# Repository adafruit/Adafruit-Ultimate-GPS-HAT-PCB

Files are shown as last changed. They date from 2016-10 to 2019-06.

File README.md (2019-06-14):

## Adafruit Ultimate GPS HAT PCB

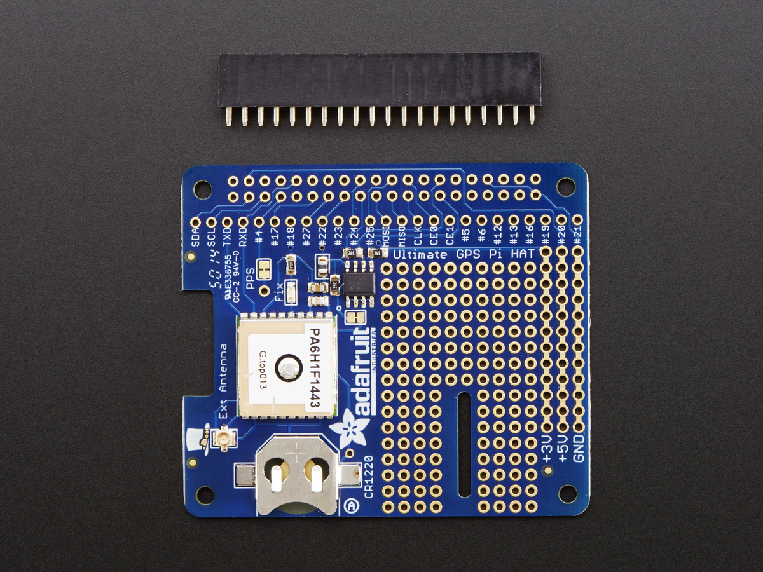
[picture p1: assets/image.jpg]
<a href="http://www.adafruit.com/products/2324"><br/>
Click here to purchase one from the Adafruit shop
</a>

PCB files for the Adafruit Ultimate GPS HAT. Format is EagleCAD schematic and board layout
- http://www.adafruit.com/product/2324

This new HAT from Adafruit adds our celebrated Ultimate GPS on it, so you can add precision time and location to your Raspberry Pi Model Pi 3, Pi Zero, A+, B+, or Pi 2 & 3

Here's the low-down on the GPS module:

-165 dBm sensitivity, 10 Hz updates, 66 channels
Only 20mA current draw
Built in Real Time Clock (RTC) - slot in a CR1220 backup battery for 7-years or more of timekeeping even if the Raspberry Pi is off!
PPS output on fix, by default connected to pin #4
Internal patch antenna which works quite well when used outdoors + u.FL connector for external active antenna for when used indoors or in locations without a clear sky view
Fix status LED blinks to let you know when the GPS has determined the current coordinates
We spun up a HAT based on our Ultimate GPS, added a coin-cell holder for RTC usage, break-outs for all the Raspberry Pi's extra pins, and plenty of prototyping area for adding LEDs, sensors, and more.

Please note, this HAT takes over the Raspberry Pi's hardware UART to send/receive data to and from the GPS module. So, if you need to use the RX/TX pins with a console cable, you cannot also use this HAT. Instead, you'll have to use a composite or HDMI monitor and keyboard to log in, or use ssh to connect over the network to your Pi. Read up on our tutorial for more information on how to use this fine HAT

Comes as a fully assembled GPS + PCB and an additional 2x20 GPIO header. Some light soldering is required to attach the 2x20 GPIO header to the HAT but it's fast and easy for anyone with a soldering iron and solder. You can also swap the plain female header we have with a 'stacky' type that lets you plug in a hat or GPIO cable on top or a slim ultra-low-profile header.

To make air-shipping eaiser, this HAT does not come with a 12mm coin battery! 

### License

Adafruit invests time and resources providing this open source design, please support Adafruit and open-source hardware by purchasing products from [Adafruit.com](https://www.adafruit.com)!

Creative Commons Attribution, Share-Alike license, check license.txt for more information All text above must be included in any redistribution - 
See license.txt for more information.

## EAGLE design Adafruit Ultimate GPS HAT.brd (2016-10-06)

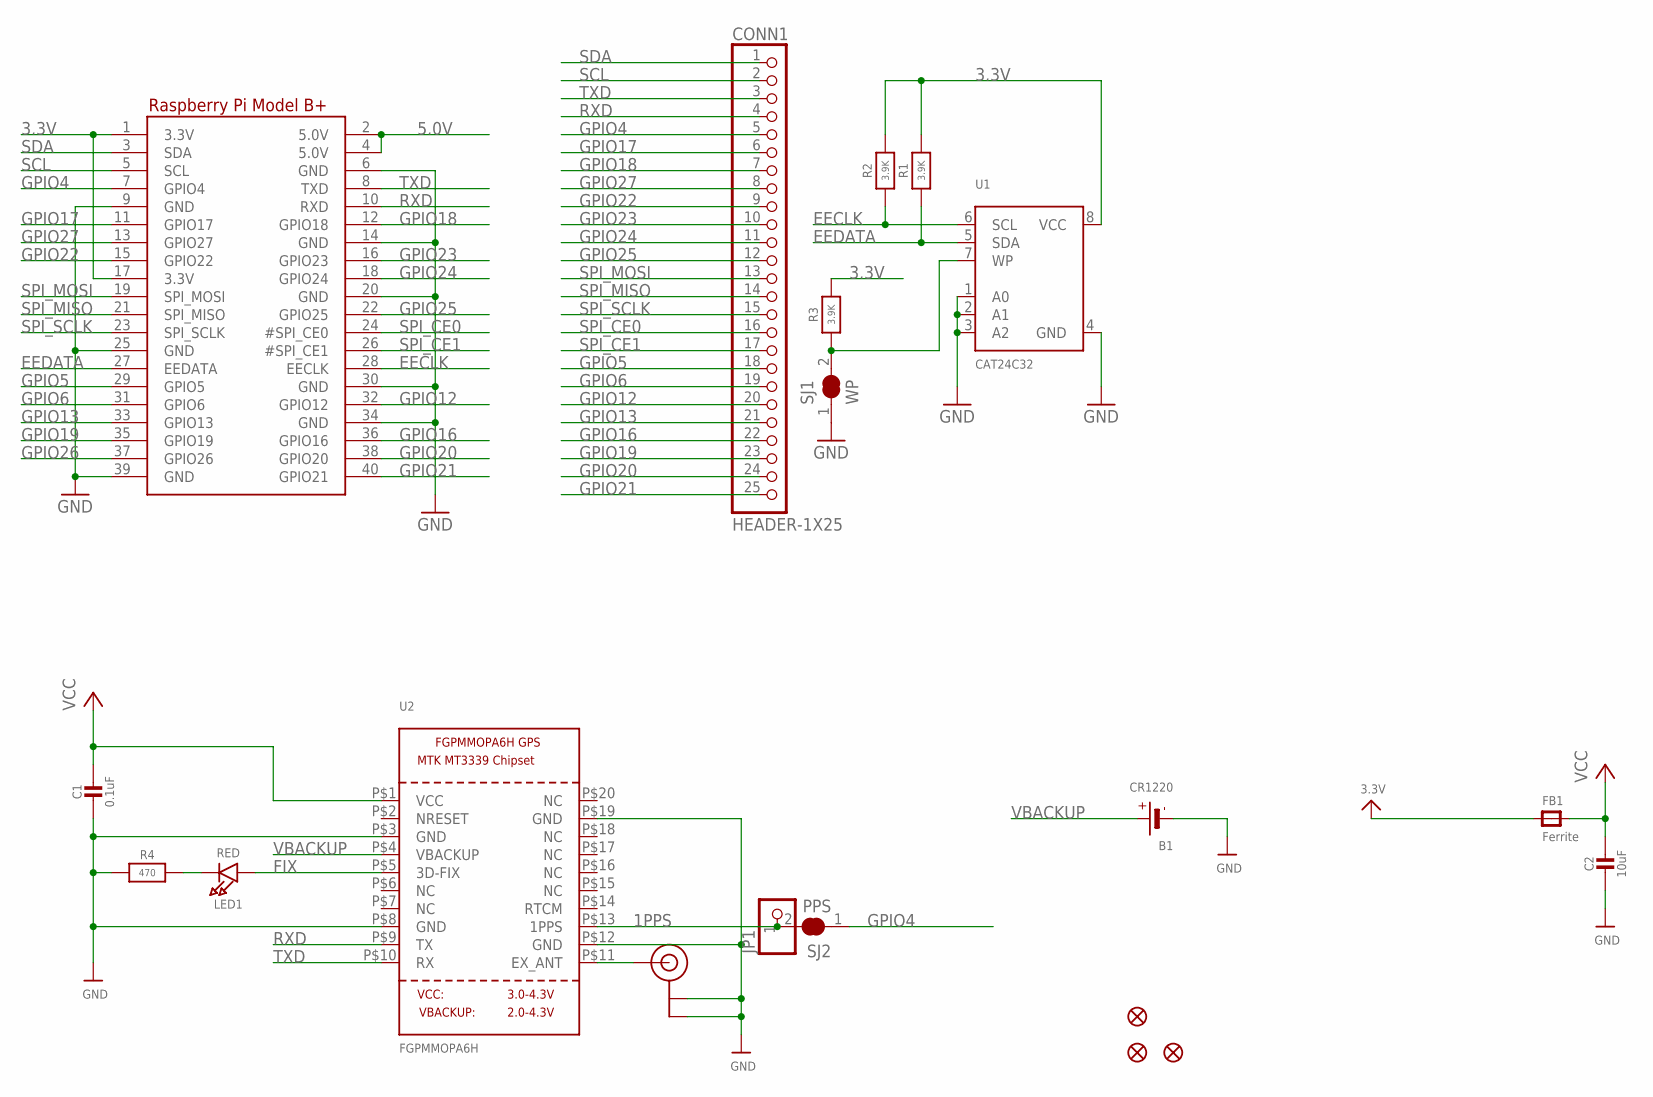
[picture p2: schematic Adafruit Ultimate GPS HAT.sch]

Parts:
B1: CR1220
C1: 0.1uF; 0805-NO
C2: 10uF; 0805-NO
CONN1: HEADER-1X25; 1X25_ROUND_70MIL
FB1: Ferrite; 0805
FID1, FID2, FID3: FIDUCIAL""; FIDUCIAL_1MM
JP1: PINHD-1X1CB; 1X01-CLEANBIG
LED1: RED; CHIPLED_0805
R1, R2, R3: 3.9K; 0805-NO
R4: 470; 0805-NO
RPI1: RASPBERRYPI_BPLUS_HATSLOTS; PI_HAT_SLOTS
SJ1: WP; SOLDERJUMPER_CLOSEDWIRE
SJ2: PPS; SOLDERJUMPER_CLOSEDWIRE
U1: CAT24C32; SOIC8_150MIL
U2: FGPMMOPA6H
U$20: U.FL

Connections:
1PPS: JP1.1, SJ2.2, U2.P$13 (1PPS)
3.3V: FB1.1, R1.2, R2.2, R3.2, RPI1.1 (3.3V), RPI1.17 (3.3V), U1.8 (VCC)
5.0V: RPI1.2 (5.0V), RPI1.4 (5.0V)
EECLK: R2.1, RPI1.28 (EECLK), U1.6 (SCL)
EEDATA: R1.1, RPI1.27 (EEDATA), U1.5 (SDA)
FIX: LED1.A, U2.P$5 (3D-FIX)
GND: B1.-, C1.2, C2.2, R4.1, RPI1.6 (GND), RPI1.9 (GND), RPI1.14 (GND), RPI1.20 (GND), RPI1.25 (GND), RPI1.30 (GND), RPI1.34 (GND), RPI1.39 (GND), SJ1.1, U1.1 (A0), U1.2 (A1), U1.3 (A2), U1.4 (GND), U2.P$3 (GND), U2.P$8 (GND), U2.P$12 (GND), U2.P$19 (GND), U$20.P$1 (GND), U$20.P$2 (GND)
GPIO4: CONN1.5, RPI1.7 (GPIO4), SJ2.1
GPIO5: CONN1.18, RPI1.29 (GPIO5)
GPIO6: CONN1.19, RPI1.31 (GPIO6)
GPIO12: CONN1.20, RPI1.32 (GPIO12)
GPIO13: CONN1.21, RPI1.33 (GPIO13)
GPIO16: CONN1.22, RPI1.36 (GPIO16)
GPIO17: CONN1.6, RPI1.11 (GPIO17)
GPIO18: CONN1.7, RPI1.12 (GPIO18)
GPIO19: CONN1.23, RPI1.35 (GPIO19)
GPIO20: CONN1.24, RPI1.38 (GPIO20)
GPIO21: CONN1.25, RPI1.40 (GPIO21)
GPIO22: CONN1.9, RPI1.15 (GPIO22)
GPIO23: CONN1.10, RPI1.16 (GPIO23)
GPIO24: CONN1.11, RPI1.18 (GPIO24)
GPIO25: CONN1.12, RPI1.22 (GPIO25)
GPIO26: RPI1.37 (GPIO26)
GPIO27: CONN1.8, RPI1.13 (GPIO27)
unnamed: R3.1, SJ1.2, U1.7 (WP)
unnamed: LED1.C, R4.2
unnamed: U2.P$11 (EX_ANT), U$20.P$3 (SIGNAL)
RXD: CONN1.4, RPI1.10 (RXD), U2.P$9 (TX)
SCL: CONN1.2, RPI1.5 (SCL)
SDA: CONN1.1, RPI1.3 (SDA)
SPI_CE0: CONN1.16, RPI1.24 (#SPI_CE0)
SPI_CE1: CONN1.17, RPI1.26 (#SPI_CE1)
SPI_MISO: CONN1.14, RPI1.21 (SPI_MISO)
SPI_MOSI: CONN1.13, RPI1.19 (SPI_MOSI)
SPI_SCLK: CONN1.15, RPI1.23 (SPI_SCLK)
TXD: CONN1.3, RPI1.8 (TXD), U2.P$10 (RX)
VBACKUP: B1.+$1 (+), U2.P$4 (VBACKUP)
VCC: C1.1, C2.1, FB1.2, U2.P$1 (VCC)

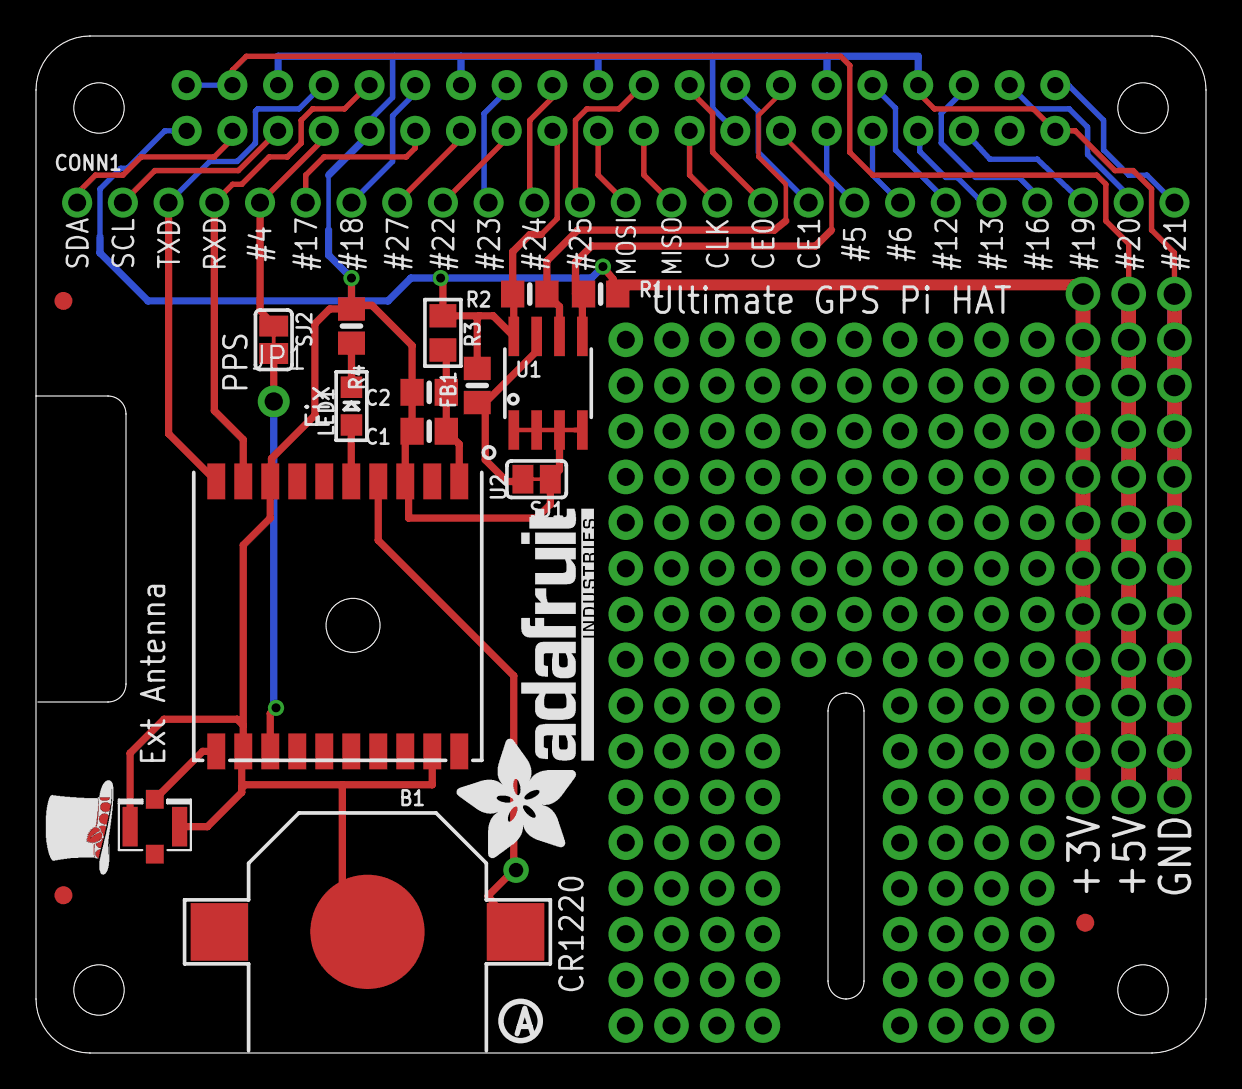
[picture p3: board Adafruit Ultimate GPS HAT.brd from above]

Board: 2 copper layers, 65.0 x 56.5 mm, 23 parts (0 on the bottom side), 37 nets.

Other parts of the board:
U$3: ADAFRUIT_TEXT_20MM
U$4: PIHATLOGO
U$6: PCBFEAT-REV-056

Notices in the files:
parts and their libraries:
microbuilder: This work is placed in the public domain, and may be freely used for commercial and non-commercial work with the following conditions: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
